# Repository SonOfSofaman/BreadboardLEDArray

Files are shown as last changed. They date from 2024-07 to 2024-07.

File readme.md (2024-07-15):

# Breadboard LED Array

I created this LED Array for use in my construction of the internet famous [Ben Eater 8-bit Computer](https://eater.net/8bit), but they could be handy for any breadboard project that requires groups of 8 LEDs.

If you wish to make your own, the files for the PCB and links to the parts can be found below. Some assembly required.

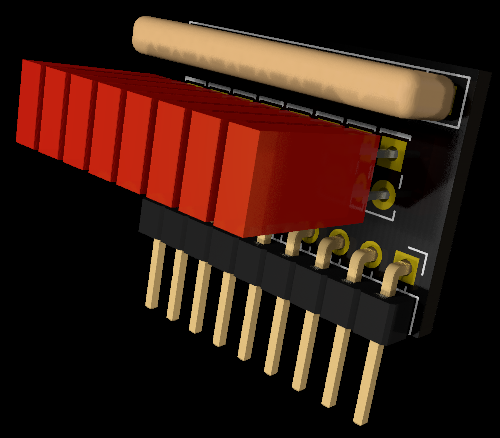
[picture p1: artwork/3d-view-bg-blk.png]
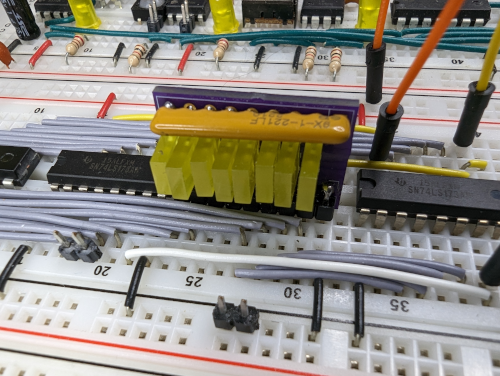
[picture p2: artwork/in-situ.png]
 

Go ahead. Laugh at my sloppy construction. I had a 3D printed assembly jig made after I did this one by hand. What a difference it made. Thanks, Luke!

## How to use

The pins are strategically arranged so you can connect the array directly to pins 2-9 (address lines) and pin 10 (ground) of a 74LS245 Bus Transceiver without any wires. To accomodate pinouts of other ICs, you could install a mix of jumper wires and header pins as needed. Use straight headers if you want the board to lie flat. I designed for minimum footprint, hence the 90° header.

The onboard resistor array limits the current to the LEDs so no external parts are needed. Use something like 680Ω, or go as high as 1k. You could use lower resistance if you like brighter LEDs but I wouldn't go below 270Ω.

## PCBs

This [GitHub repository](https://github.com/SonOfSofaman/BreadboardLEDArray) contains the [KiCad 7](https://www.kicad.org/) files for the circuit board. Also included are the Gerber files if you want to fabricate your own boards. See the /fab folder.

Use this [project link](https://oshpark.com/shared_projects/hIeStv3n) to purchase the boards from [OSH Park](https://oshpark.com/).

## Parts

Use this [parts list](https://www.mouser.com/ProjectManager/ProjectDetail.aspx?AccessID=65f5e81664) if you want to buy the LEDs and/or resistors from [Mouser](https://mouser.com).

[BreadboardLEDArray](https://github.com/SonOfSofaman/BreadboardLEDArray) © 2023 by [SofaTronics / SonOfSofaman](https://sofatronics.io/) is licensed under [CC BY-NC-SA 4.0](https://creativecommons.org/licenses/by-nc-sa/4.0/?ref=chooser-v1)

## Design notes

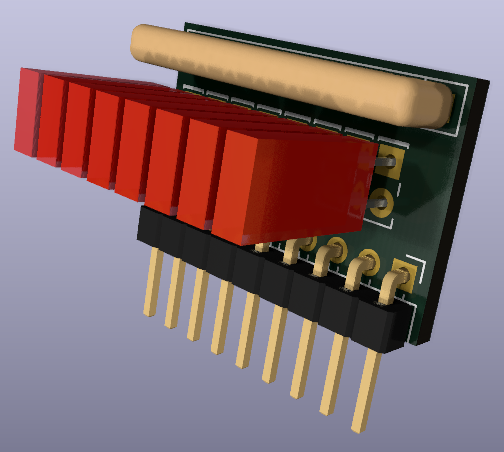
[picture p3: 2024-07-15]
artwork/3d-view.png

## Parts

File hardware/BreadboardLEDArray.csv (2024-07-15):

Source: | C:\Users\Joel\Projects\BreadboardLEDArray\BreadboardLEDArray.kicad_sch
Date: | 2023-05-13 06:58:05
Tool: | Eeschema 7.0.2
Generator: | C:\Program Files\KiCad\7.0\bin\scripting\plugins/bom_csv_grouped_by_value_with_fp.py
Component Count: | 10
Ref | Qnty | Value | Cmp name | Footprint | Description | Vendor | DNP
D1, D2, D3, D4, D5, D6, D7, D8 | 8 | LED | LED | LED_THT:LED_Rectangular_W5.0mm_H2.0mm | Light emitting diode
J1 | 1 | 9x1 pin header | Conn_01x09 | Connector_PinHeader_2.54mm:PinHeader_1x09_P2.54mm_Horizontal | Generic connector, single row, 01x09, script generated (kicad-library-utils/schlib/autogen/connector/)
RN1 | 1 | 270 ohm resistor network | R_Network08_US | Resistor_THT:R_Array_SIP9 | 8 resistor network, star topology, bussed resistors, small US symbol

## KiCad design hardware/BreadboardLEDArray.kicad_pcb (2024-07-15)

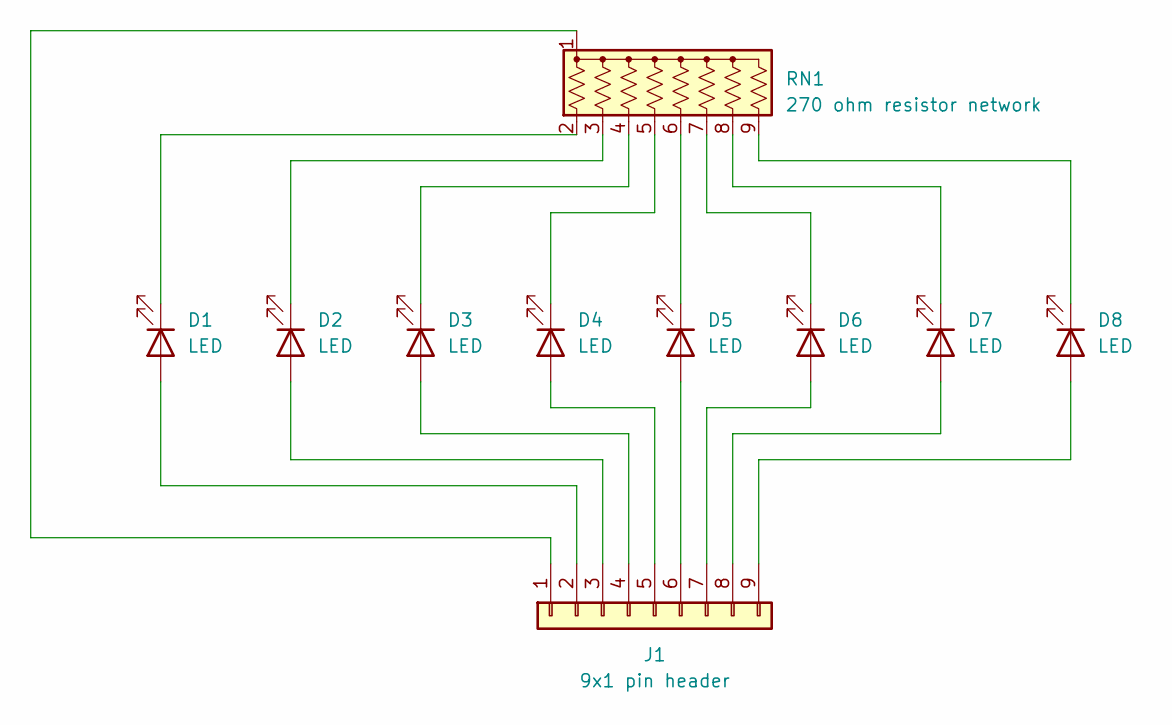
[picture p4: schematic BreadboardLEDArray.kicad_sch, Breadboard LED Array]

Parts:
D1, D2, D3, D4, D5, D6, D7, D8: LED; LED_Rectangular_W5.0mm_H2.0mm
J1: 9x1 pin header; PinHeader_1x09_P2.54mm_Horizontal
RN1: 270 ohm resistor network; R_Array_SIP9

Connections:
unnamed: D1.2 (A), J1.2
unnamed: D1.1 (K), RN1.2 (R1)
unnamed: D2.2 (A), J1.3
unnamed: D2.1 (K), RN1.3 (R2)
unnamed: D3.2 (A), J1.4
unnamed: D3.1 (K), RN1.4 (R3)
unnamed: D4.2 (A), J1.5
unnamed: D4.1 (K), RN1.5 (R4)
unnamed: D5.2 (A), J1.6
unnamed: D5.1 (K), RN1.6 (R5)
unnamed: D6.2 (A), J1.7
unnamed: D6.1 (K), RN1.7 (R6)
unnamed: D7.2 (A), J1.8
unnamed: D7.1 (K), RN1.8 (R7)
unnamed: D8.2 (A), J1.9
unnamed: D8.1 (K), RN1.9 (R8)
unnamed: J1.1, RN1.1 (common)

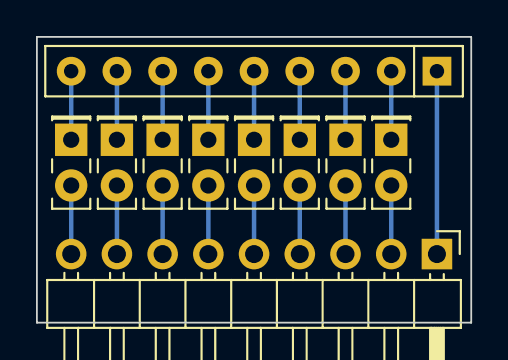
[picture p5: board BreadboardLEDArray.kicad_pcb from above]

Board: 2 copper layers, 24.1 x 15.9 mm, 10 parts (0 on the bottom side), 17 nets.

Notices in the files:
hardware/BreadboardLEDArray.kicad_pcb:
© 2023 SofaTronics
